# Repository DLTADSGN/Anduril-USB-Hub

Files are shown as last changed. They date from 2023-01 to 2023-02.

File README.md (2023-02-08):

# Anduril USB Hub
This project is a USB 2.0 Hub with USB C input and three output ports (2 USB A, 1 USB C).

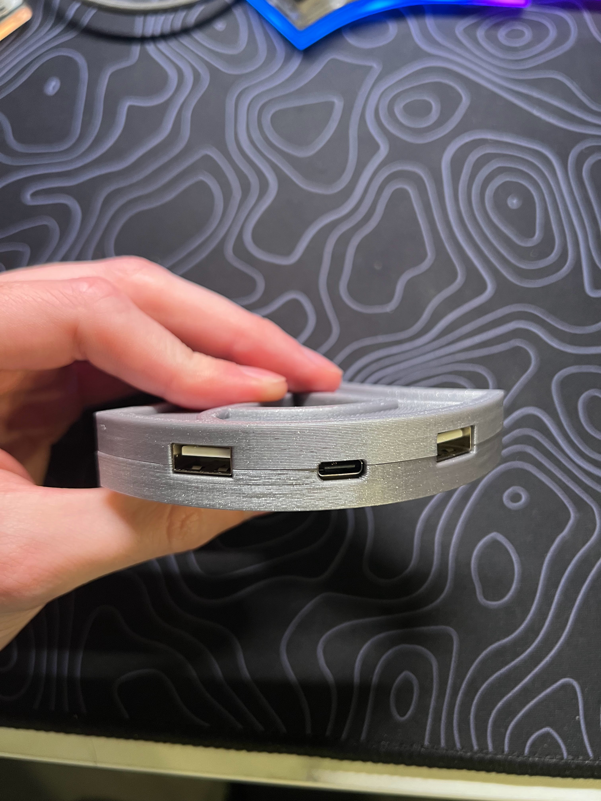
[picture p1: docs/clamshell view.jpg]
Output Ports
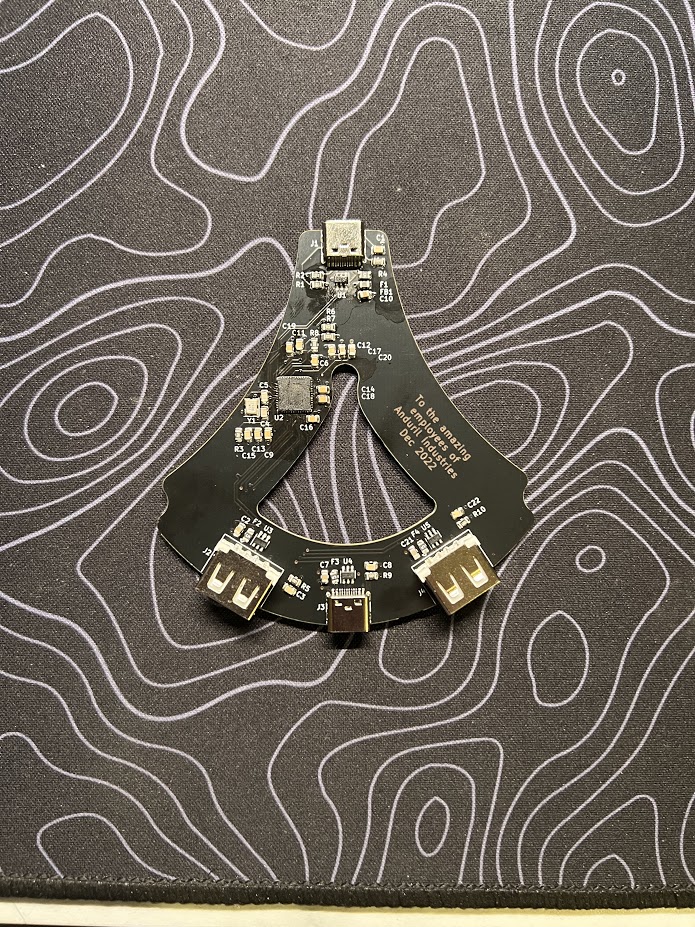
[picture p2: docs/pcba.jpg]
PCBA
Full Assembly  

There isn't much novel about this USB Hub, the main challenge was the layout and packaging to get it to fit in the shape of the [Anduril Industries](https://www.anduril.com/) logo:

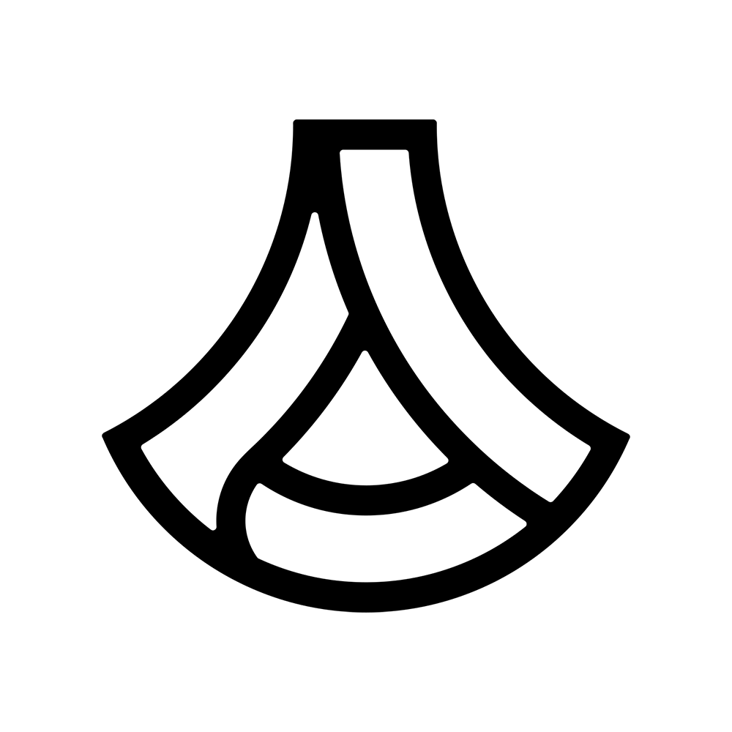
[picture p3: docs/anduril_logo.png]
Anduril Industries Logo


The PCB is designed to fit in a 3D printed, two part housing that screws together to make the Anduril Industries logo. The upstream/host of the hub is at the top and the downstream/peripheral ports are at the bottom.

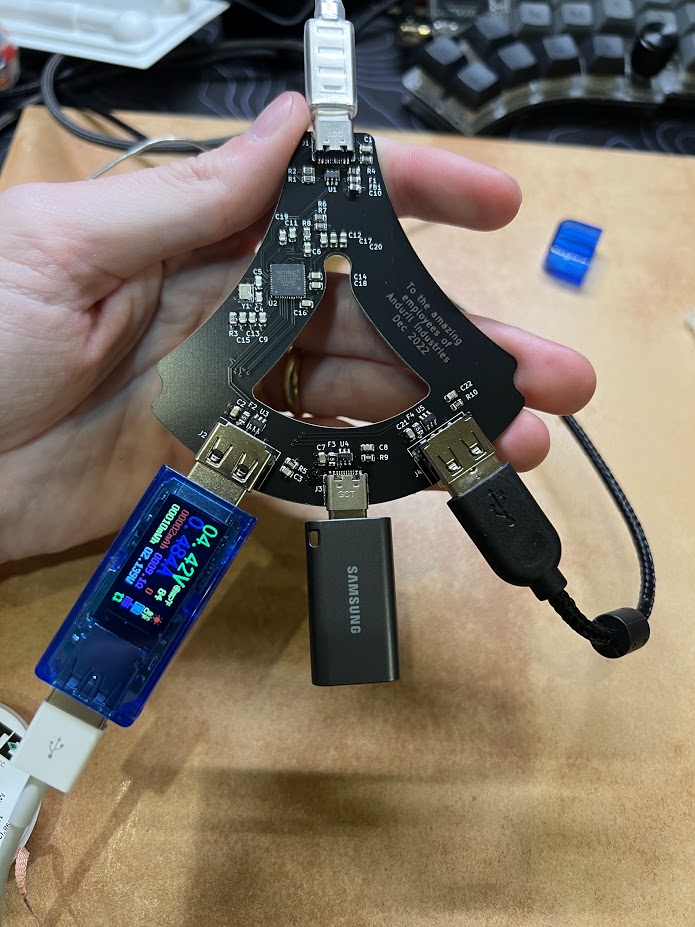
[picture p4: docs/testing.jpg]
Anduril Industries Logo 
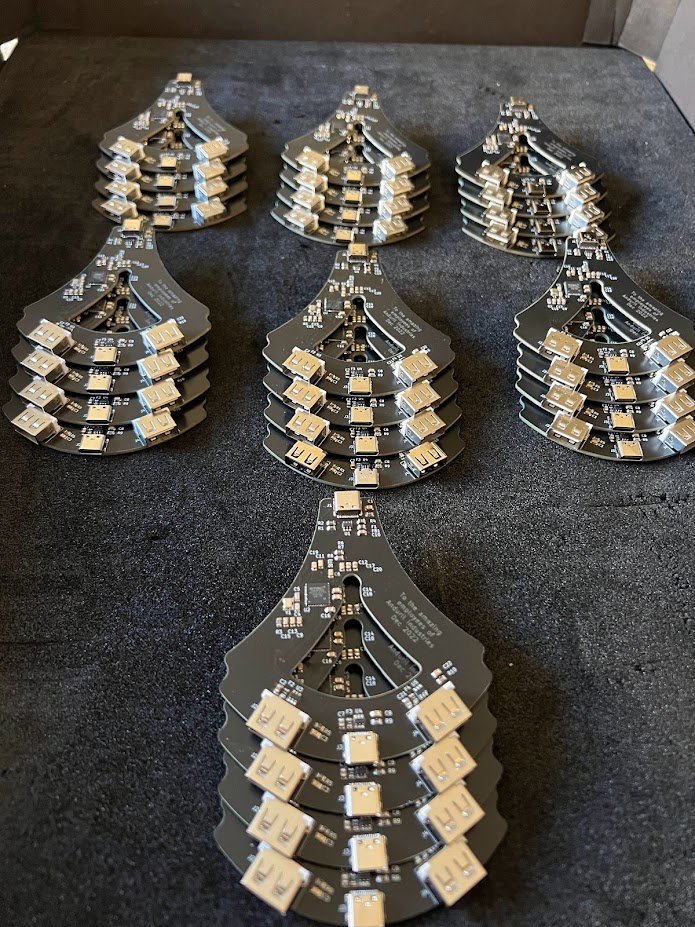
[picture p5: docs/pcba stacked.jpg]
Completed PCBAs


## **REQUIREMENTS**:
 - **USB 2.0 minimum**: USB 3.0+ is outside of my skill set currently, so I stuck with USB 2.0 which should be fast enough for most peripherals and data transfer.
 - **A and C ports**: This was trivial but allows the hub to be used for all sorts of devices, including USB C flash drives.
 - **Safety**: Since this is a gift to my coworkers, I wanted the upmost confidence that the devices they plugged in would not get fried by my creation. To ensure this, I added TVS diodes and fuses on every connector for surge protection and over-current protection.
 - **3D printed enclosure**: Since I just got a 3D printer, I wanted to use it to make the housings in the shape of the Anduril logo. This provided me some great practice/challenge in designing PCBs with mechanical constraints. Additionally, this helped me refine a workflow for electro-mechanical integration.

## **WISHLIST**:
### v1.2
- controlled impedence/differential pair routing
- better testing procedure
- downstream UCB C resistors
- fix silkscreen for fuses
### v2.0
- 2 layer for cheaper manufacturing
- controlled impedence/differential pair routing
- better IC selection (USB2514)

## **LICENSE**:
There is **NO** license for reproduction of the Anduril logo. I do not have any rights or permission to reproduce the Anduril logo in any form and am making this at my own risk.

The electronics of Anduril USB Hub</span> by <a xmlns:cc="http://creativecommons.org/ns#" href="https://github.com/colonDdesigns" property="cc:attributionName" rel="cc:attributionURL">colonDdesigns</a> is licensed under a <a rel="license" href="http://creativecommons.org/licenses/by-nc-sa/4.0/">Creative Commons Attribution-NonCommercial-ShareAlike 4.0 International License</a>.

[][cc-by-nc-sa]

[cc-by-nc-sa]: http://creativecommons.org/licenses/by-nc-sa/4.0/
[cc-by-nc-sa-image]: https://licensebuttons.net/l/by-nc-sa/4.0/88x31.png

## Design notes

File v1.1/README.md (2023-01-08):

# Anduril USB Hub
 
[mechanical](./mechanical/) for Solidworks/STEP files

[electrical](./electrical/) for KiCad files/schematic

[manufacturing](./manufacturing/) for gerbers/BOM/3D print files

enjoy!

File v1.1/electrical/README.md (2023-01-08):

# Electrical

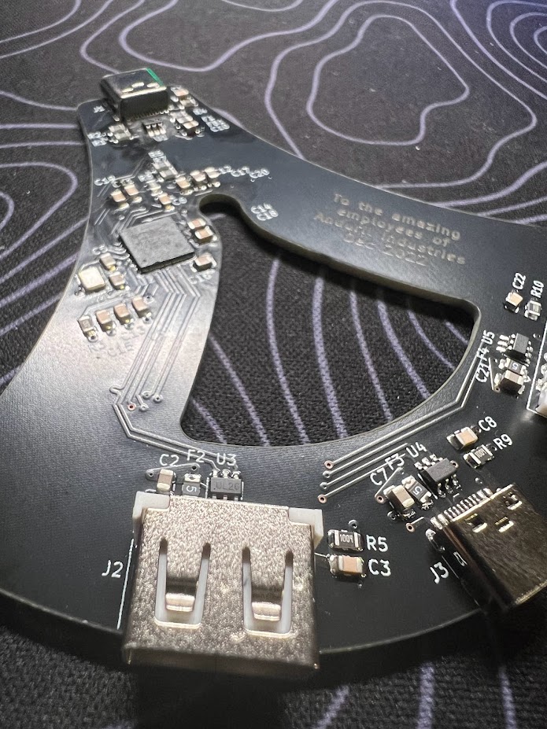
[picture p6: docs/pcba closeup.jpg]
PCBA closeup
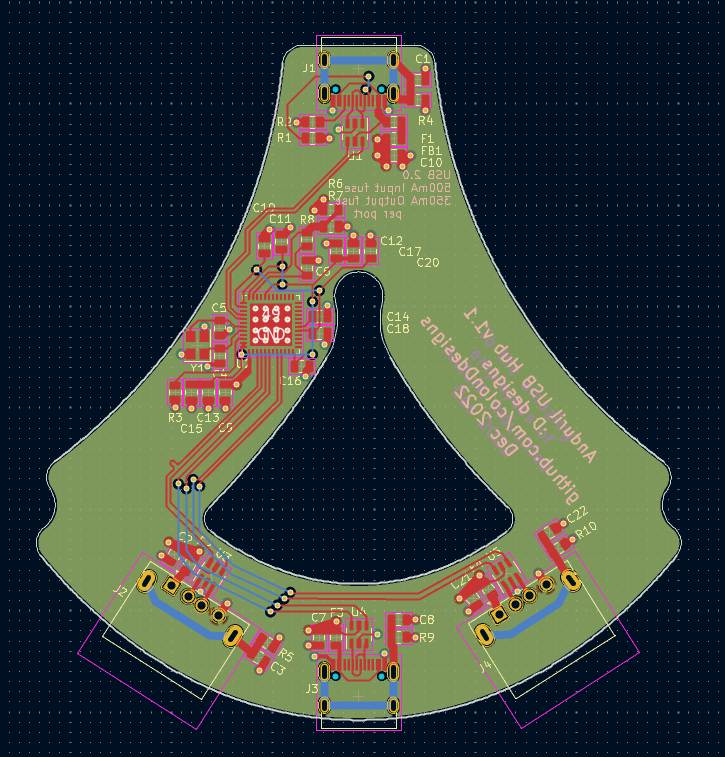
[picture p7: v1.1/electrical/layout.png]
Layout
 PCBA  

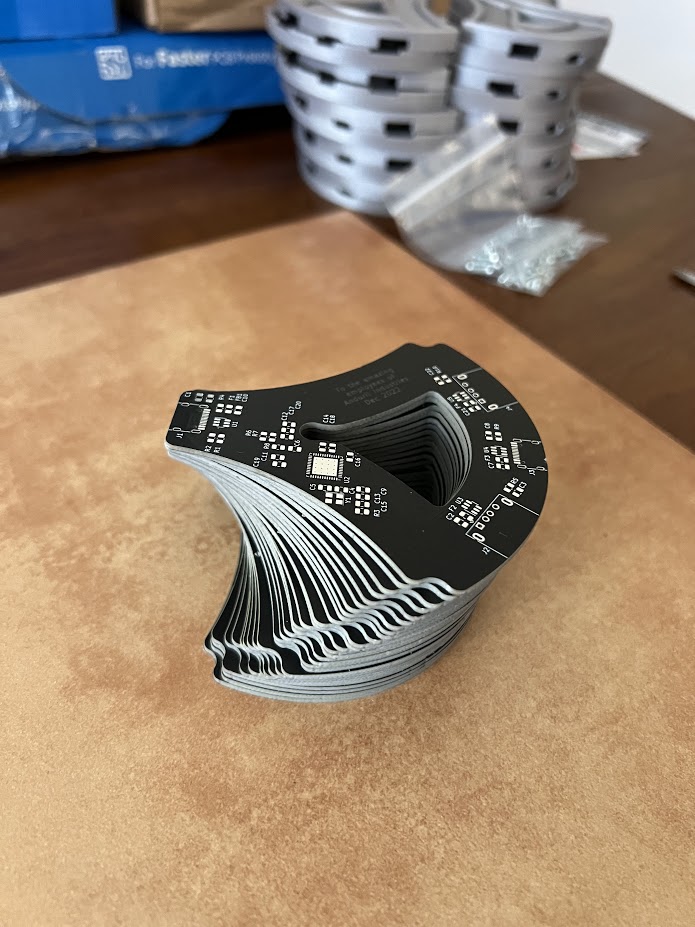
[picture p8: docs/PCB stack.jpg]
PCB Stack
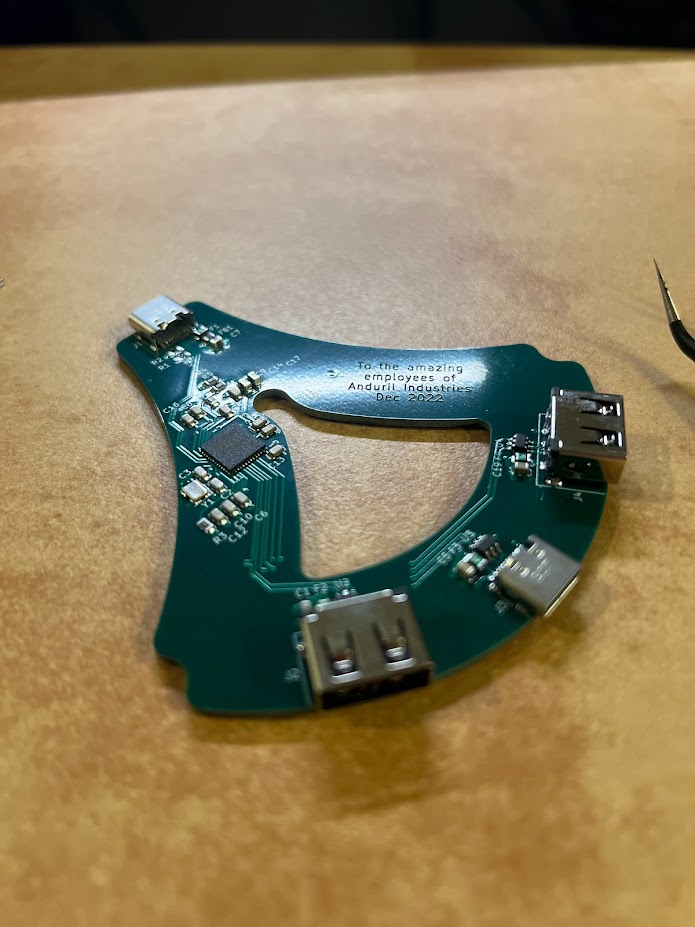
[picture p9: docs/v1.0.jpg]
v1.0
 Testing

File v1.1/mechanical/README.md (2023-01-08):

# Mechanical

Upper and Lower PCBA in Lower 

Black and Silver Port View

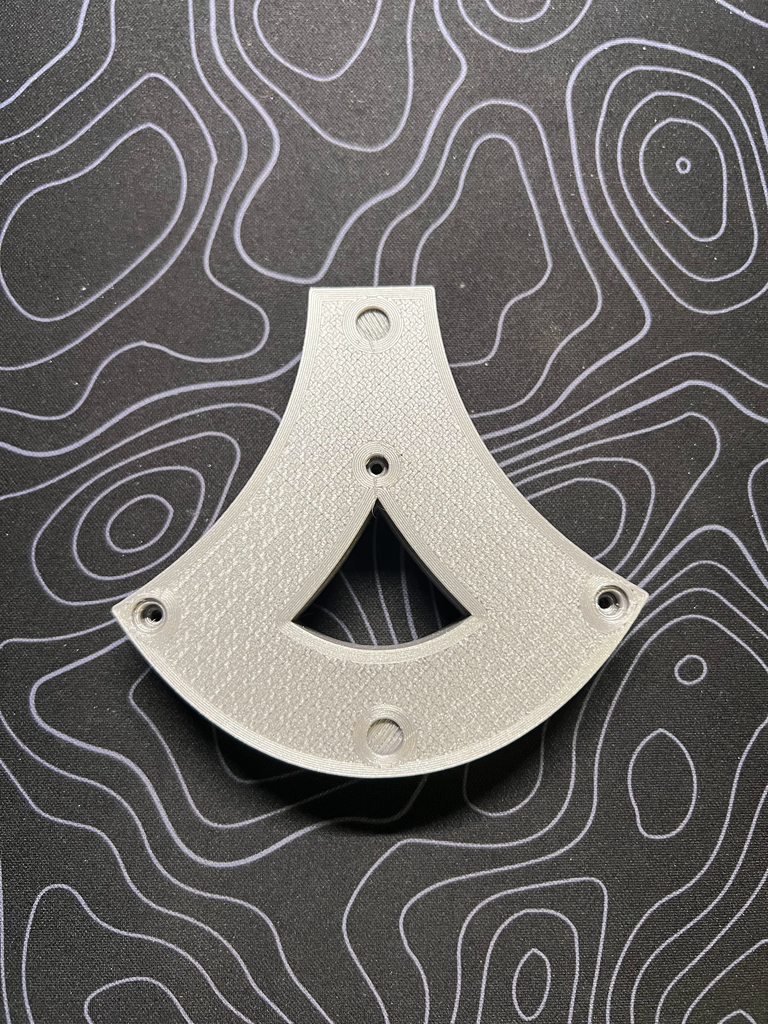
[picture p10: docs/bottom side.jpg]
Bottom Side
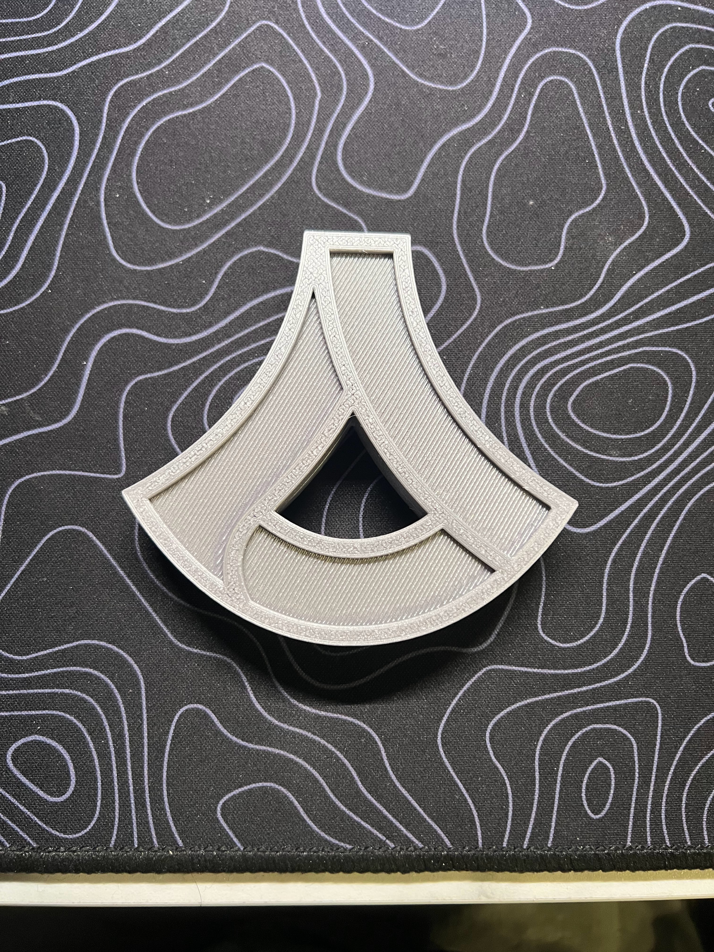
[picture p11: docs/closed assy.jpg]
Top Side


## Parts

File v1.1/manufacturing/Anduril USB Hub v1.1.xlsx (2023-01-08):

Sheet: v1.1 Detail BOM
Anduril USB Hub
Assembly | Description/Use | Manufactuer | Manufactuerer PN | Vendor | Vendor PN | Qty Needed per 1 Assy | Qty Needed per 25 Assy | Qty per 1 Order | Cost per 1 Order | Qty ordered | Total Qty ordered | Cost ext | Link | Package/Footprint | Datasheet | Notes | Order # | Tracking # | Status | ETA
PCB Component | USB Controller IC | Microchip | USB4604-1080HN | Mouser | 579-USB4604-1080HN | 1 | 25 | 1 | 5.39 | 27 | 27 | 145.53 | https://www.mouser.com/ProductDetail/Microchip-Technology-Atmel/USB4604-1080HN?qs=Yyy8avaXlIsjmKTrefWvVw%3D%3D | SQFN-48 | https://www.mouser.com/datasheet/2/268/000001716C_-1512886.pdf | -
PCB Component | 24MHz Crystal | JGHC | S3224000081040D1JB | LCSC | C700764 | 1 | 25 | 5 | 0.38 | 6 | 30 | 2.28 | https://www.lcsc.com/product-detail/Crystals_JGHC-S3224000081040D1JB_C700764.html | SMD3225-4P | https://datasheet.lcsc.com/lcsc/2008261934_JGHC-S3224000081040D1JB_C700764.pdf | -
PCB Component | 5k1Ohm Resistor | UNI-ROYAL | 0805W8F5101T5E | LCSC | C27834 | 2 | 50 | 100 | 0.17 | 1 | 100 | 0.17 | https://www.lcsc.com/product-detail/Chip-span-style-background-color-ff0-Resistor-span-Surface-Mount_UNI-ROYAL-Uniroyal-Elec-0805W8F5101T5E_C27834.html | 0805 | https://datasheet.lcsc.com/lcsc/2206010030_UNI-ROYAL-Uniroyal-Elec-0805W8F5101T5E_C27834.pdf | -
PCB Component | 10kOhm Resistor | UNI-ROYAL | 0805W8F1002T5E | LCSC | C17414 | 1 | 25 | 100 | 0.08 | 1 | 100 | 0.08 | https://www.lcsc.com/product-detail/Chip-span-style-background-color-ff0-Resistor-span-Surface-Mount_UNI-ROYAL-Uniroyal-Elec-0805W8F1002T5E_C17414.html | 0805 | https://datasheet.lcsc.com/lcsc/2206010216_UNI-ROYAL-Uniroyal-Elec-0805W8F1002T5E_C17414.pdf | -
PCB Component | 12kOhm Resistor | UNI-ROYAL | 0805W8F1202T5E | LCSC | C17444 | 1 | 25 | 100 | 0.17 | 1 | 100 | 0.17 | https://www.lcsc.com/product-detail/Chip-span-style-background-color-ff0-Resistor-span-Surface-Mount_UNI-ROYAL-Uniroyal-Elec-0805W8F1202T5E_C17444.html | 0805 | https://datasheet.lcsc.com/lcsc/2206010216_UNI-ROYAL-Uniroyal-Elec-0805W8F1202T5E_C17444.pdf | -
PCB Component | 51kOhm Resistor | UNI-ROYAL | 0805W8F5102T5E | LCSC | C17737 | 1 | 25 | 100 | 0.16 | 1 | 100 | 0.16 | https://www.lcsc.com/product-detail/Chip-span-style-background-color-ff0-Resistor-span-Surface-Mount_UNI-ROYAL-Uniroyal-Elec-0805W8F5102T5E_C17737.html | 0805 | https://datasheet.lcsc.com/lcsc/2206010200_UNI-ROYAL-Uniroyal-Elec-0805W8F5102T5E_C17737.pdf | -
PCB Component | 100kOhm Resistor | UNI-ROYAL | 0805W8F1003T5E | LCSC | C149504 | 1 | 25 | 100 | 0.17 | 1 | 100 | 0.17 | https://www.lcsc.com/product-detail/Chip-span-style-background-color-ff0-Resistor-span-Surface-Mount_UNI-ROYAL-Uniroyal-Elec-0805W8F1003T5E_C149504.html | 0805 | https://datasheet.lcsc.com/lcsc/2205312316_UNI-ROYAL-Uniroyal-Elec-0805W8F1003T5E_C149504.pdf | -
PCB Component | 1MOhm Resistor | UNI-ROYAL | 0805W8F1004T5E | LCSC | C17514 | 4 | 100 | 100 | 0.17 | 2 | 200 | 0.34 | https://www.lcsc.com/product-detail/Chip-Resistor-Surface-Mount_UNI-ROYAL-Uniroyal-Elec-0805W8F1004T5E_C17514.html | 0805 | https://datasheet.lcsc.com/lcsc/2206010200_UNI-ROYAL-Uniroyal-Elec-0805W8F1004T5E_C17514.pdf | -
PCB Component | 8pF Capacitor | FH | 0805CG8R0C500NT | LCSC | C1839 | 2 | 50 | 100 | 0.56 | 1 | 100 | 0.56 | https://www.lcsc.com/product-detail/Multilayer-Ceramic-Capacitors-MLCC-SMD-SMT_FH-Guangdong-Fenghua-Advanced-Tech-0805CG8R0C500NT_C1839.html | 0805 | https://datasheet.lcsc.com/lcsc/1811061741_FH--Guangdong-Fenghua-Advanced-Tech-0805CG8R0C500NT_C1839.pdf | -
PCB Component | 0.1uF Capacitor | Torch | C0805B104K500NT | LCSC | C476766 | 14 | 350 | 100 | 0.38 | 4 | 400 | 1.52 | https://www.lcsc.com/product-detail/Multilayer-Ceramic-Capacitors-MLCC-SMD-SMT_TORCH-C0805B104K500NT_C476766.html | 0805 | https://datasheet.lcsc.com/lcsc/1912300933_TORCH-C0805B104K500NT_C476766.pdf | -
PCB Component | 1uF Capacitor | Samsung Electro-Mechanics | CL21B105KBFNNNE | LCSC | C28323 | 3 | 75 | 50 | 0.43 | 2 | 100 | 0.86 | https://www.lcsc.com/product-detail/Multilayer-Ceramic-Capacitors-MLCC-SMD-SMT_Samsung-Electro-Mechanics-CL21B105KBFNNNE_C28323.html | 0805 | https://datasheet.lcsc.com/lcsc/1810191216_Samsung-Electro-Mechanics-CL21B105KBFNNNE_C28323.pdf | -
PCB Component | 4.7uF Capacitor | Samsung Electro-Mechanics | CL21A475KAQNNNE | LCSC | C1779 | 3 | 75 | 50 | 0.5 | 2 | 100 | 1 | https://www.lcsc.com/product-detail/Multilayer-Ceramic-Capacitors-MLCC-SMD-SMT_Samsung-Electro-Mechanics-CL21A475KAQNNNE_C1779.html | 0805 | https://datasheet.lcsc.com/lcsc/1810261822_Samsung-Electro-Mechanics-CL21A475KAQNNNE_C1779.pdf | -
PCB Component | 750mA Fuse | Brightking | SMD0805B075TF | LCSC | C269105 | 3 | 75 | 20 | 0.42 | 5 | 100 | 2.1 | https://www.lcsc.com/product-detail/Resettable-Fuses_Brightking-SMD0805B075TF_C269105.html | 0805 | https://datasheet.lcsc.com/lcsc/1808280518_Brightking-SMD0805B075TF_C269105.pdf | -
PCB Component | 1.1A Fuse | Brightking | SMD0805B110TF | LCSC | C269107 | 1 | 25 | 20 | 0.58 | 2 | 40 | 1.16 | https://www.lcsc.com/product-detail/Resettable-Fuses_Brightking-SMD0805B110TF_C269107.html | 0805 | https://datasheet.lcsc.com/lcsc/1810161745_Brightking-SMD0805B110TF_C269107.pdf | -
PCB Component | TVS Diode | TECH PUBLIC | USBLC6-2SC6 | LCSC | C2827654 | 4 | 100 | 10 | 0.66 | 12 | 120 | 7.92 | https://www.lcsc.com/product-detail/ESD-Protection-Devices_TECH-PUBLIC-USBLC6-2SC6_C2827654.html | SOT-23-6 | https://datasheet.lcsc.com/lcsc/2108132230_TECH-PUBLIC-USBLC6-2SC6_C2827654.pdf | -
PCB Component | USB A Connector | Jing Extension of the Electronic Co | 912-221A1011D10100 | LCSC | C42459 | 2 | 50 | 10 | 0.47 | 6 | 60 | 2.82 | https://www.lcsc.com/product-detail/USB-Connectors_Jing-Extension-of-the-Electronic-Co-912-221A1011D10100_C42459.html | Connector | https://datasheet.lcsc.com/lcsc/2102261734_Jing-Extension-of-the-Electronic-Co--912-221A1011D10100_C42459.pdf | -
PCB Component | USB C Connector | Korean Hroparts Elec | TYPE-C-31-M-12 | LCSC | C165948 | 2 | 50 | 5 | 1.14 | 11 | 55 | 12.54 | https://www.lcsc.com/product-detail/USB-Connectors_Korean-Hroparts-Elec-TYPE-C-31-M-12_C165948.html | Connector | https://datasheet.lcsc.com/lcsc/2205251630_Korean-Hroparts-Elec-TYPE-C-31-M-12_C165948.pdf | -
PCB Component | 600Ohm Ferrite Bead | Sunlord | GZ2012D601TF | LCSC | C1017 | 1 | 25 | 50 | 0.45 | 1 | 50 | 0.45 | https://www.lcsc.com/product-detail/span-style-background-color-ff0-Ferrite-span-Beads_Sunlord-GZ2012D601TF_C1017.html | 0805 | https://datasheet.lcsc.com/lcsc/2109181830_Sunlord-GZ2012D601TF_C1017.pdf | -
PCB Fab | PCB Board + Stencil | JLCPCB | - | JLCPCB | - | 1 | 25 | 1 | 56.54 | 25 | 25 | 56.54 | - | - | - | -
Hardware | M2 Heat Set Insert | Hilitchi | - | Amazon | B07VBRF7P2 | 3 | 75 | 100 | 7.99 | 1 | 100 | 7.99 | https://www.amazon.com/dp/B07VBRF7P2?ref=ppx_yo2ov_dt_b_product_details&th=1 | - |  | -
Hardware | M2x4mm SHCS | - | - | Anduril | - | 2 | 50 | 100 | 15.76 | 1 | 100 | 15.76 | - | - | - | -
Hardware | M2x6mm SHCS | - | - | Anduril | - | 1 | 25 | 100 | 9.97 | 1 | 100 | 9.97 | - | - | - | -
Hardware | Bumpons, 6mm x 2mm | - | - | Amazon | B073SVKFYJ | 4 | 100 | 200 | 5.99 | 1 | 200 | 5.99 | https://www.amazon.com/gp/product/B073SVKFYJ/ref=ppx_od_dt_b_asin_title_s00?ie=UTF8&th=1 | - | - | -
Hardware | USB Housing, Lower | :D Designs | - | - | - | 1 | 25 | 1 | 0.4 | 25 | 25 | 10 | - | - | - | -
Hardware | USB Housing, Upper | :D Designs | - | - | - | 1 | 25 | 1 | 0.4 | 25 | 25 | 10 | - | - | - | -
Tooling | Heat Set Insert Tips | - | - | Amazon | B08B17VQLD | 1 | 1 | 1 | 19.95 | 1 | 1 | 19.95 | - | - | - | -
Tooling | USB C Male Terminal | - | - | Amazon | B08D93ZSM4 | 2 | 2 | 1 | 7.5 | 2 | 2 | 15 | https://www.amazon.com/gp/product/B08D93ZSM4/ref=ppx_yo_dt_b_asin_title_o00_s00?ie=UTF8&th=1 | - | - | -
Tooling | USB A Male Terminal | - | - | Amazon | B0BPC7DZM1 | 2 | 2 | 2 | 10.99 | 1 | 2 | 10.99 | https://www.amazon.com/gp/product/B0BPC7DZM1/ref=ppx_yo_dt_b_asin_title_o00_s00?ie=UTF8&psc=1 | - | - | -
Tooling | Putty Knife | - | - | Amazon | B09955YQJQ | 1 | 1 | 1 | 7.79 | 1 | 1 | 7.79 | https://www.amazon.com/dp/B09955YQJQ?psc=1&ref=ppx_yo2ov_dt_b_product_details | - | - | -
Consumable | 3D Printer Filament, Matte Black | Overture 3D | - | Amazon | B089S2QDHD | 1 | 1 | 1 | 15.99 | 1 | 1 | - | https://www.amazon.com/gp/product/B089S2QDHD/ref=ppx_od_dt_b_asin_title_s01?ie=UTF8&th=1 | - | - | -
Consumable | Green Stickers | Avery | - | Amazon | B0000859WQ | 1 | 1 | 450 | 3.41 | 1 | 450 | 3.41 | https://www.amazon.com/gp/product/B0000859WQ/ref=ppx_od_dt_b_asin_title_s00?ie=UTF8&th=1 | - | - | -
Consumable | Solder Paste | Chip Quik | TS391AX50 | Mouser | 910-TS391AX50 | 1 | 1 | 15g | 13.95 | 1 | 1 | 13.95 | https://www.mouser.com/ProductDetail/Chip-Quik/TS391AX50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 | - | https://www.mouser.com/datasheet/2/73/TS391AX250-1150217.pdf | -
 |  |  |  |  |  |  |  |  |  |  | Total | 367.17 | 14.69
 |  |  |  |  |  |  |  |  |  |  |  | 115 | 19.29

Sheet: v1.1 Fab
Designator | Value
C1, C3, C6, C8, C9, C11, C12, C13, C14, C15, C16, C18, C19, C22, | .1uF
C2, C7, C21, | 1uF
C4, C5, | 8pF
C10, C17, C20, | 4.7uF
F1, | 1.1A
F2, F3, F4, | 750mA
FB1, | 600Ohm
R1, R2, | 5k1Ohm | 0805W8F5101T5E
R3, | 12kOhm | 0805W8F1202T5E
R4, R5, R9, R10, | 1MOhm | 0805W8F1004T5E
R6, | 50kOhm | 0805W8F5102T5E
R7, | 100kOhm | 0805W8F1003T5E
R8, | 10kOhm | 0805W8F1002T5E
U1, U3, U4, U5, | USBLC6-2SC6
U2, | USB4604-1080HN
Y1, | 24MHz

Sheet: LCSC BOM Export
Total Qty Ordered | Mfr PN | LSCS PN
30 | S3224000081040D1JB | C700764
100 | 0805W8F5101T5E | C27834
100 | 0805W8F1002T5E | C17414
100 | 0805W8F1202T5E | C17444
100 | 0805W8F5102T5E | C17737
100 | 0805W8F1003T5E | C149504
200 | 0805W8F1004T5E | C17514
100 | 0805CG8R0C500NT | C1839
400 | C0805B104K500NT | C476766
100 | CL21B105KBFNNNE | C28323
100 | CL21A475KAQNNNE | C1779
40 | SMD0805B050TF | C269104
80 | SMD0805B035TF | C269103
100 | USBLC6-2SC6 | C2827654
60 | 912-221A1011D10100 | C42459
55 | TYPE-C-31-M-12 | C165948
50 | GZ2012D601TF | C1017

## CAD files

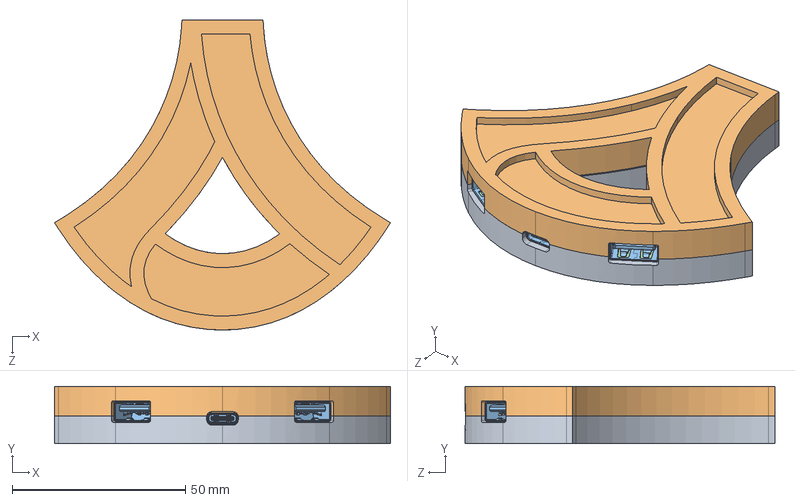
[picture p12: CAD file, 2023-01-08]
v1.1/mechanical/solidworks parts/Assembly, USB Hub.SLDASM
97.1 x 16.5 x 89.6 mm
USB Hub Housing, Lower
USB Hub Housing, Upper
Anduril USB Hub Full - Import 12-7_new
PCB Footprint

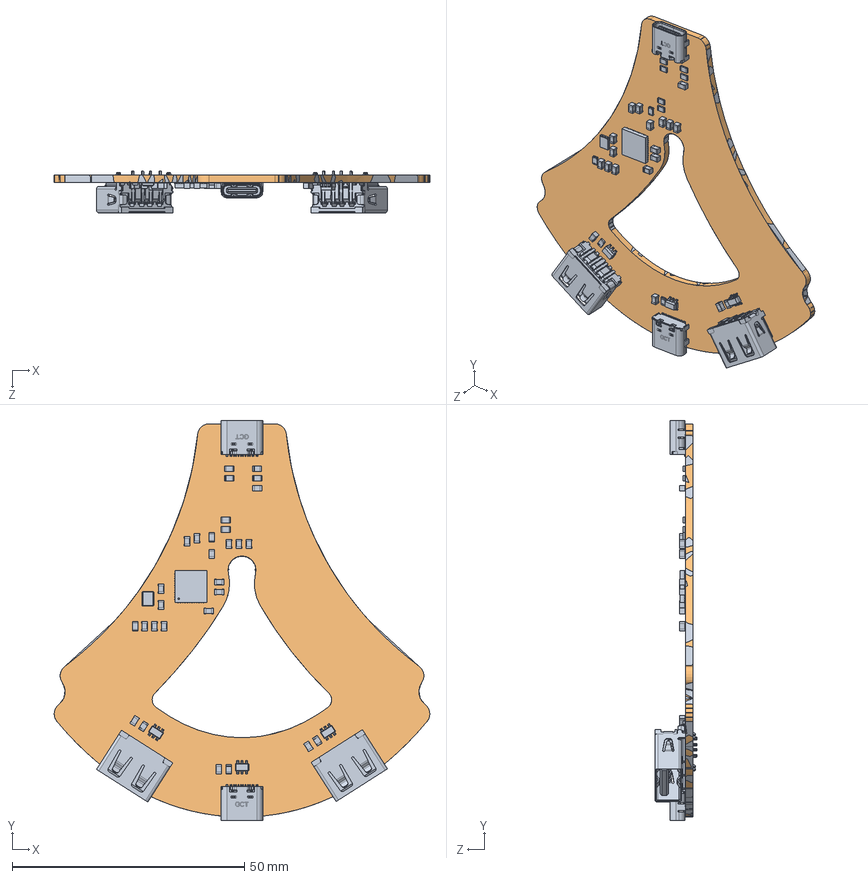
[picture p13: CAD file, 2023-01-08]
v1.1/mechanical/solidworks parts/Assebmly, PCB.SLDASM
80.8 x 86.1 x 9.01 mm
Anduril USB Hub Full - Import 12-7_new
PCB Footprint

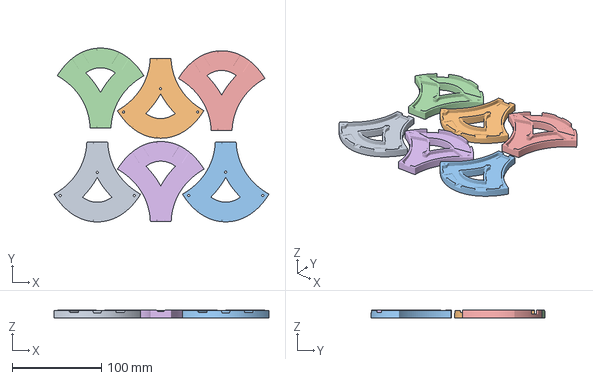
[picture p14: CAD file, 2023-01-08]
v1.1/manufacturing/USB Hub Housing.3mf
241.2 x 195.0 x 8.50 mm
USB Hub Housing, Lower v1.4.STL
USB Hub Housing, Upper v1.5.STL

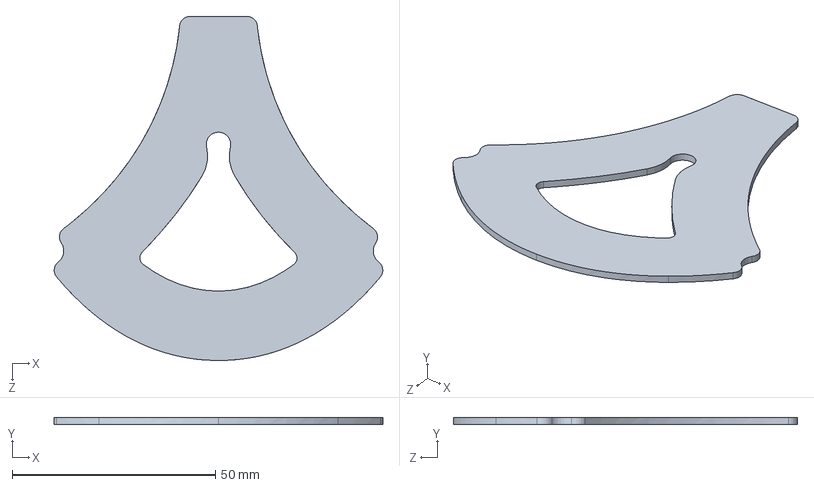
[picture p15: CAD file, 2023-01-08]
v1.1/mechanical/solidworks parts/PCB Footprint.SLDPRT
80.8 x 1.60 x 84.6 mm

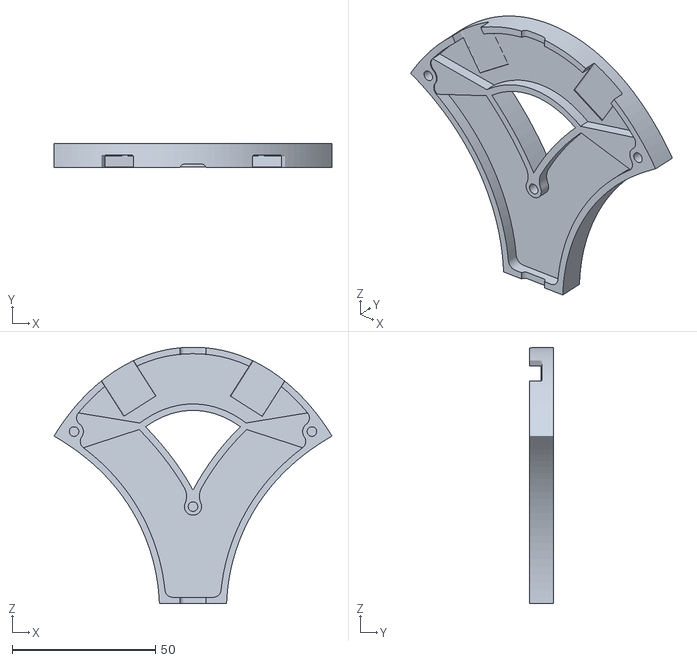
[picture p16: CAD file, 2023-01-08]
v1.1/mechanical/USB Hub Housing, Upper v1.5.STL
97.1 x 8.50 x 89.6

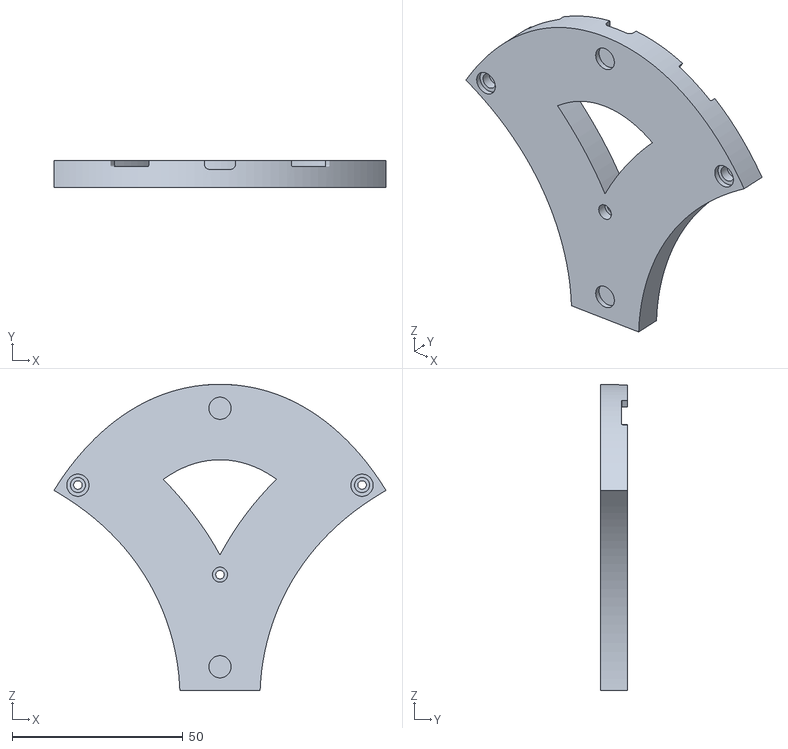
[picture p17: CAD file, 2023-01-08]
v1.1/mechanical/USB Hub Housing, Lower v1.4.STL
97.1 x 8.00 x 89.6

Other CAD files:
v1.1/mechanical/solidworks parts/USB Hub Housing, Upper.SLDPRT
v1.1/mechanical/solidworks parts/USB Hub Housing, Lower.SLDPRT

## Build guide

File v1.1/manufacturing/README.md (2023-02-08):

# Manufacturing

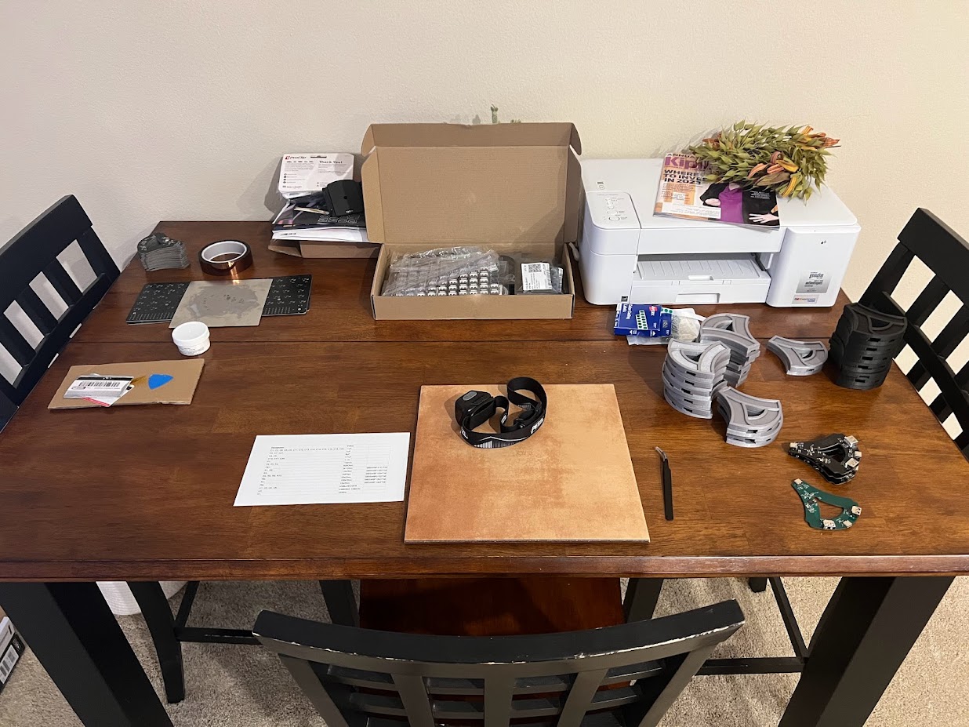
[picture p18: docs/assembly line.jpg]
Assembly Line


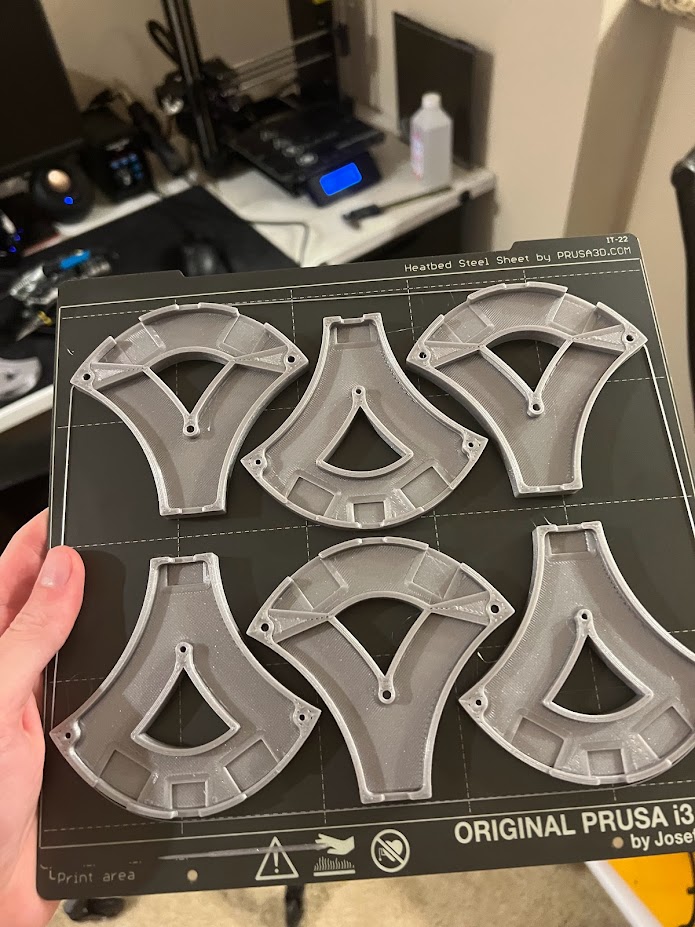
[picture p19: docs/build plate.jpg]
Build Plate
 PCB Stack

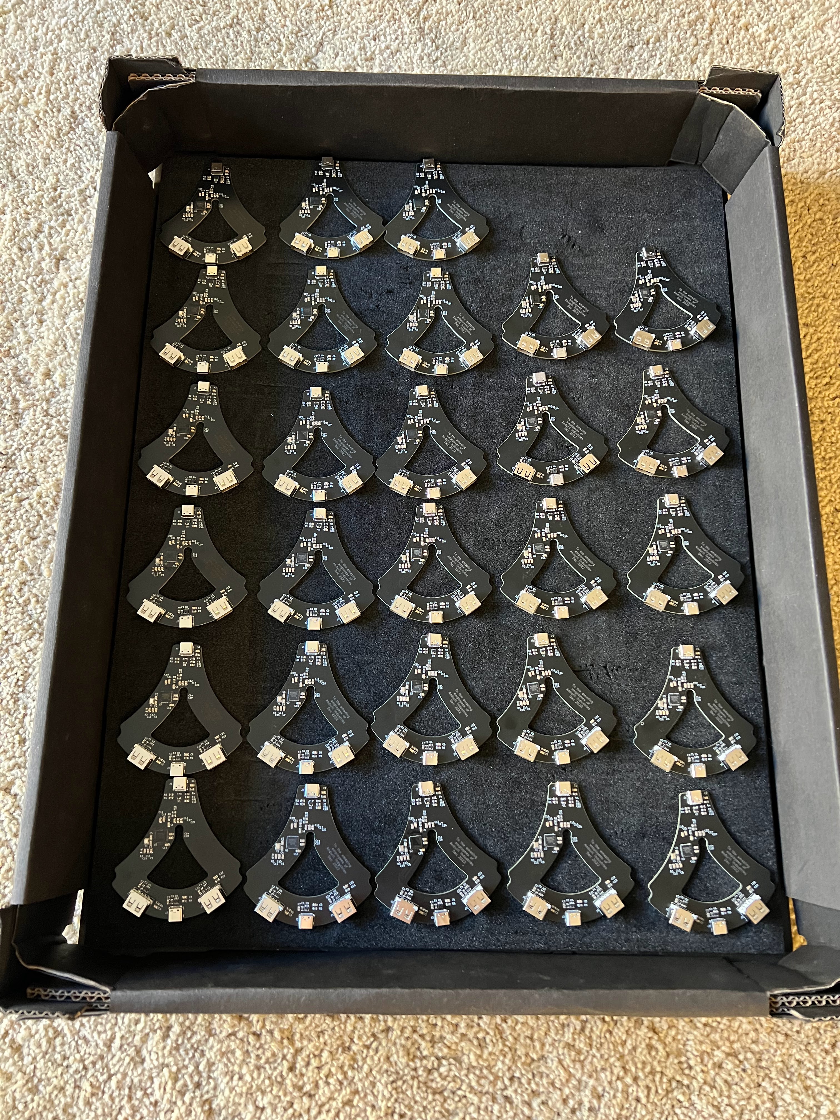
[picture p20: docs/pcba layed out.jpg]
 Completed PCBAs

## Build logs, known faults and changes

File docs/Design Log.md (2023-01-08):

# Electrical
 
- **why USB4604?** Microchip hub controllers had great documentation and application notes so I wanted to go with one of their options. When I started the project the only IC in stock on Mouser/Digikey was the USB4604. I found out when purchasing v1.1 that the USB2514 was available from LCSC for half the cost and a smaller package. Lesson learned...

- **why 4 layer board?** When designing v1.0, I saw that purchasing from JLCPCB at qty 5 was minimal cost difference between 2 vs 4 layer, so I started on a 4 layer stack. It was only when I tried to order at qty 15+ that I realized that JLCPCB added a fixed charge which significantly increased the cost. The design is definitely doable on a 2 layer board, but 4 layer gives a little more solution space. I didn't change to 2 layer for v1.1 because I didn't want to risk changing too much from my successful v1.0.

- **general workflow** I knew I wanted to make a USB Hub in the triangular shape of the Anduril logo, and make it as small as posisble to make it usbale as a usb hub. After importing the logo into solidworks I roughly got a rough housing drawn around the PCB. From there, I imported the PCB outline into KiCad and began designing. This was a big mistake because I still needed to fine tune the size and shape of the PCB and the housing. This meant I needed to redo the layout/routing eachtime I modified the housing. It would have been better if I had fully finalized the mechanicals of the housing and PCB and just did layout and routing one time. This isnt super realistic, but with some better understanding of the rough sizes of the components and one rough pass at just the layout, I couldve cut down a lot of design cycles by finishing the housing and pcb, and then finalizing the layout and completing the routing. additionally, i couldve probably spent more time finalizing the details of the housing (port openings, heat set insert sizing, clearances and interfaces). i spent a lot (too much) time exporting the pcb from KiCAD, to the housing file in Solidworks. Theres definitely some optimization to the workflow there that will ahppen naturally as my inuition and vision for designs improves. i'm very happy with how it turned out and learned a lot about the workflow and integration of pcbs and mechanical housings. the back and forth between KiCAD and SW was exacerbated by the tight constraints on the sizing.

after finalizing the pcb and housing design, i worked on optimizing the 3D printing of th housings since i was going to make 25. because of the qunaitiy, i couldn't modify each and every one in order to make it perfect, otherwise that would take too much time. so the parts need to come off the printer consistently and ready to be assembled. I had to dial in the support material settings to speed up the post processing and ensure consistent results visually. I could nest 3 sets of housings per build plate, which would take 7 hours to print. so by printing overnight, taking off in the morning and starting another print to run during the day. i could print 6 per 24 hours at a 100% yield rate! post processing time was about 3-5 mins per for support removal, heat set insert insertion, and any minor touchups.

- fuses on inputs (500mA upstream and 350mA downstream)
- tvs diodes on all inputs

- 4 layer board
    - signal
    - gnd
    - power
    - signal

- if i routed power i couldve done the perfereed stack of:
    - signal
    - gnd
    - gnd
    - signal

- 0805 components for handplacing, minimal benefit to smaller components
- did not do impedence matching, figured it would be fine without it and v1.0 worked fine without it. tried to match trace lengths. would like to understand more about impedence matching since it seems critical for robust designs

- needed to make housing tighter on pcb for better fit
- make heatset insert holes bigger to minimize the filament squeeze out
- wall thickness to match mulitple of nozzle thickness 

- 2 part housing seemed easiest to design
    - didnt see a need to hold down the PCB in any other way beyond the outer edges and connectors
    - easiest to print with minimal supports
- bumpon feet, hidden screws
- heat set inserts
- extra perimeters to minimize printed spikes that cause gaps in the housing

im sure theres a lot more i'm forgetting. will maybe add to this... please reach out with questions.

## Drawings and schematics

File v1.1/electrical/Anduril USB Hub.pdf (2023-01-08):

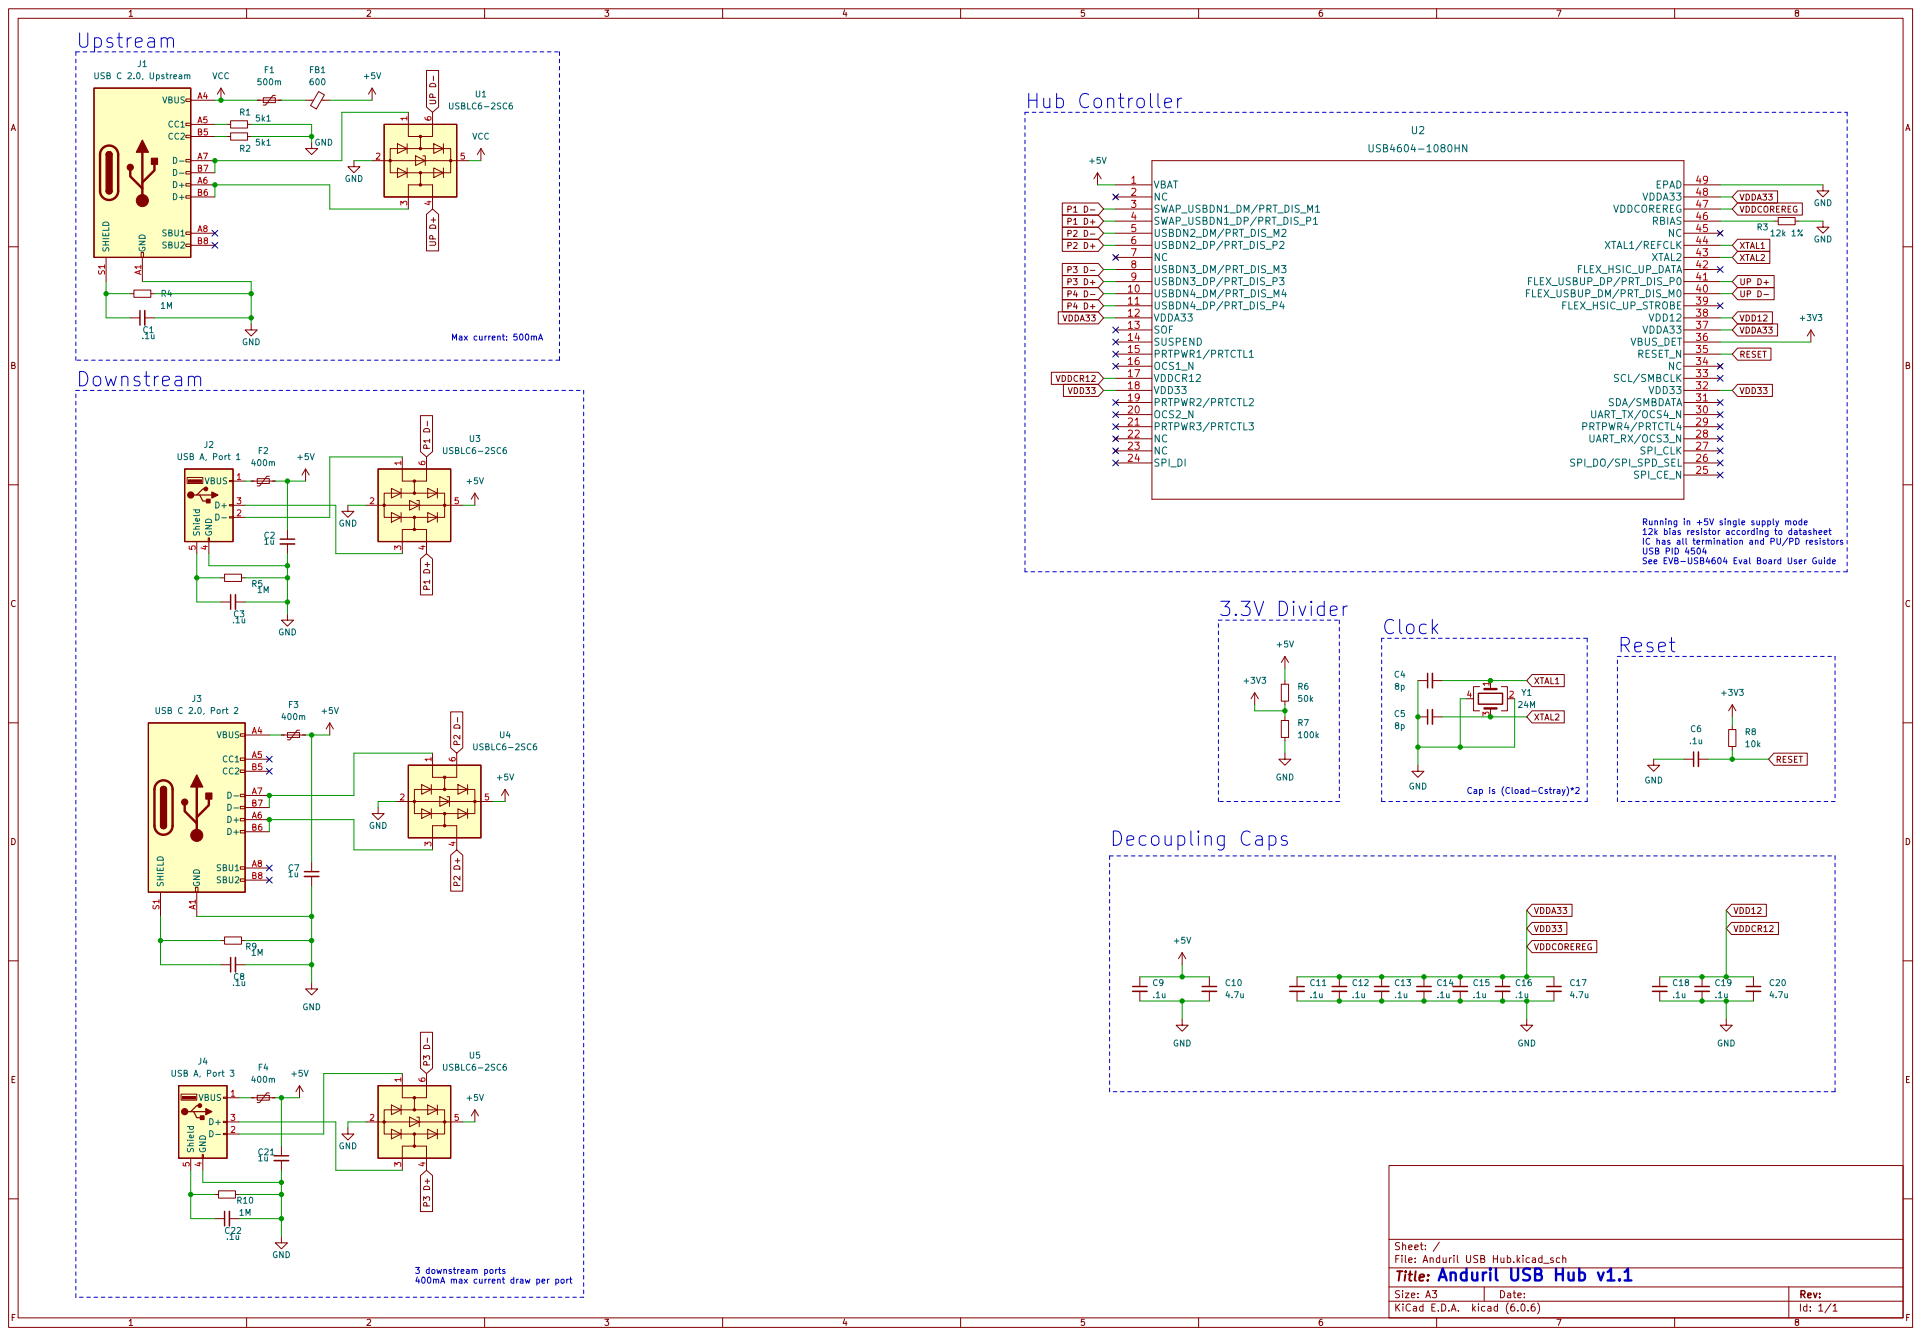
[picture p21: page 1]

Running in +5V single supply mode
12k bias resistor according to datasheet
IC has all termination and PU/PD resistors USB PID 4504 See EVB-USB4604 Eval Board User Guide

Cap is (Cload-Cstray)*2

File: Anduril USB Hub.kicad_sch Sheet: / C21

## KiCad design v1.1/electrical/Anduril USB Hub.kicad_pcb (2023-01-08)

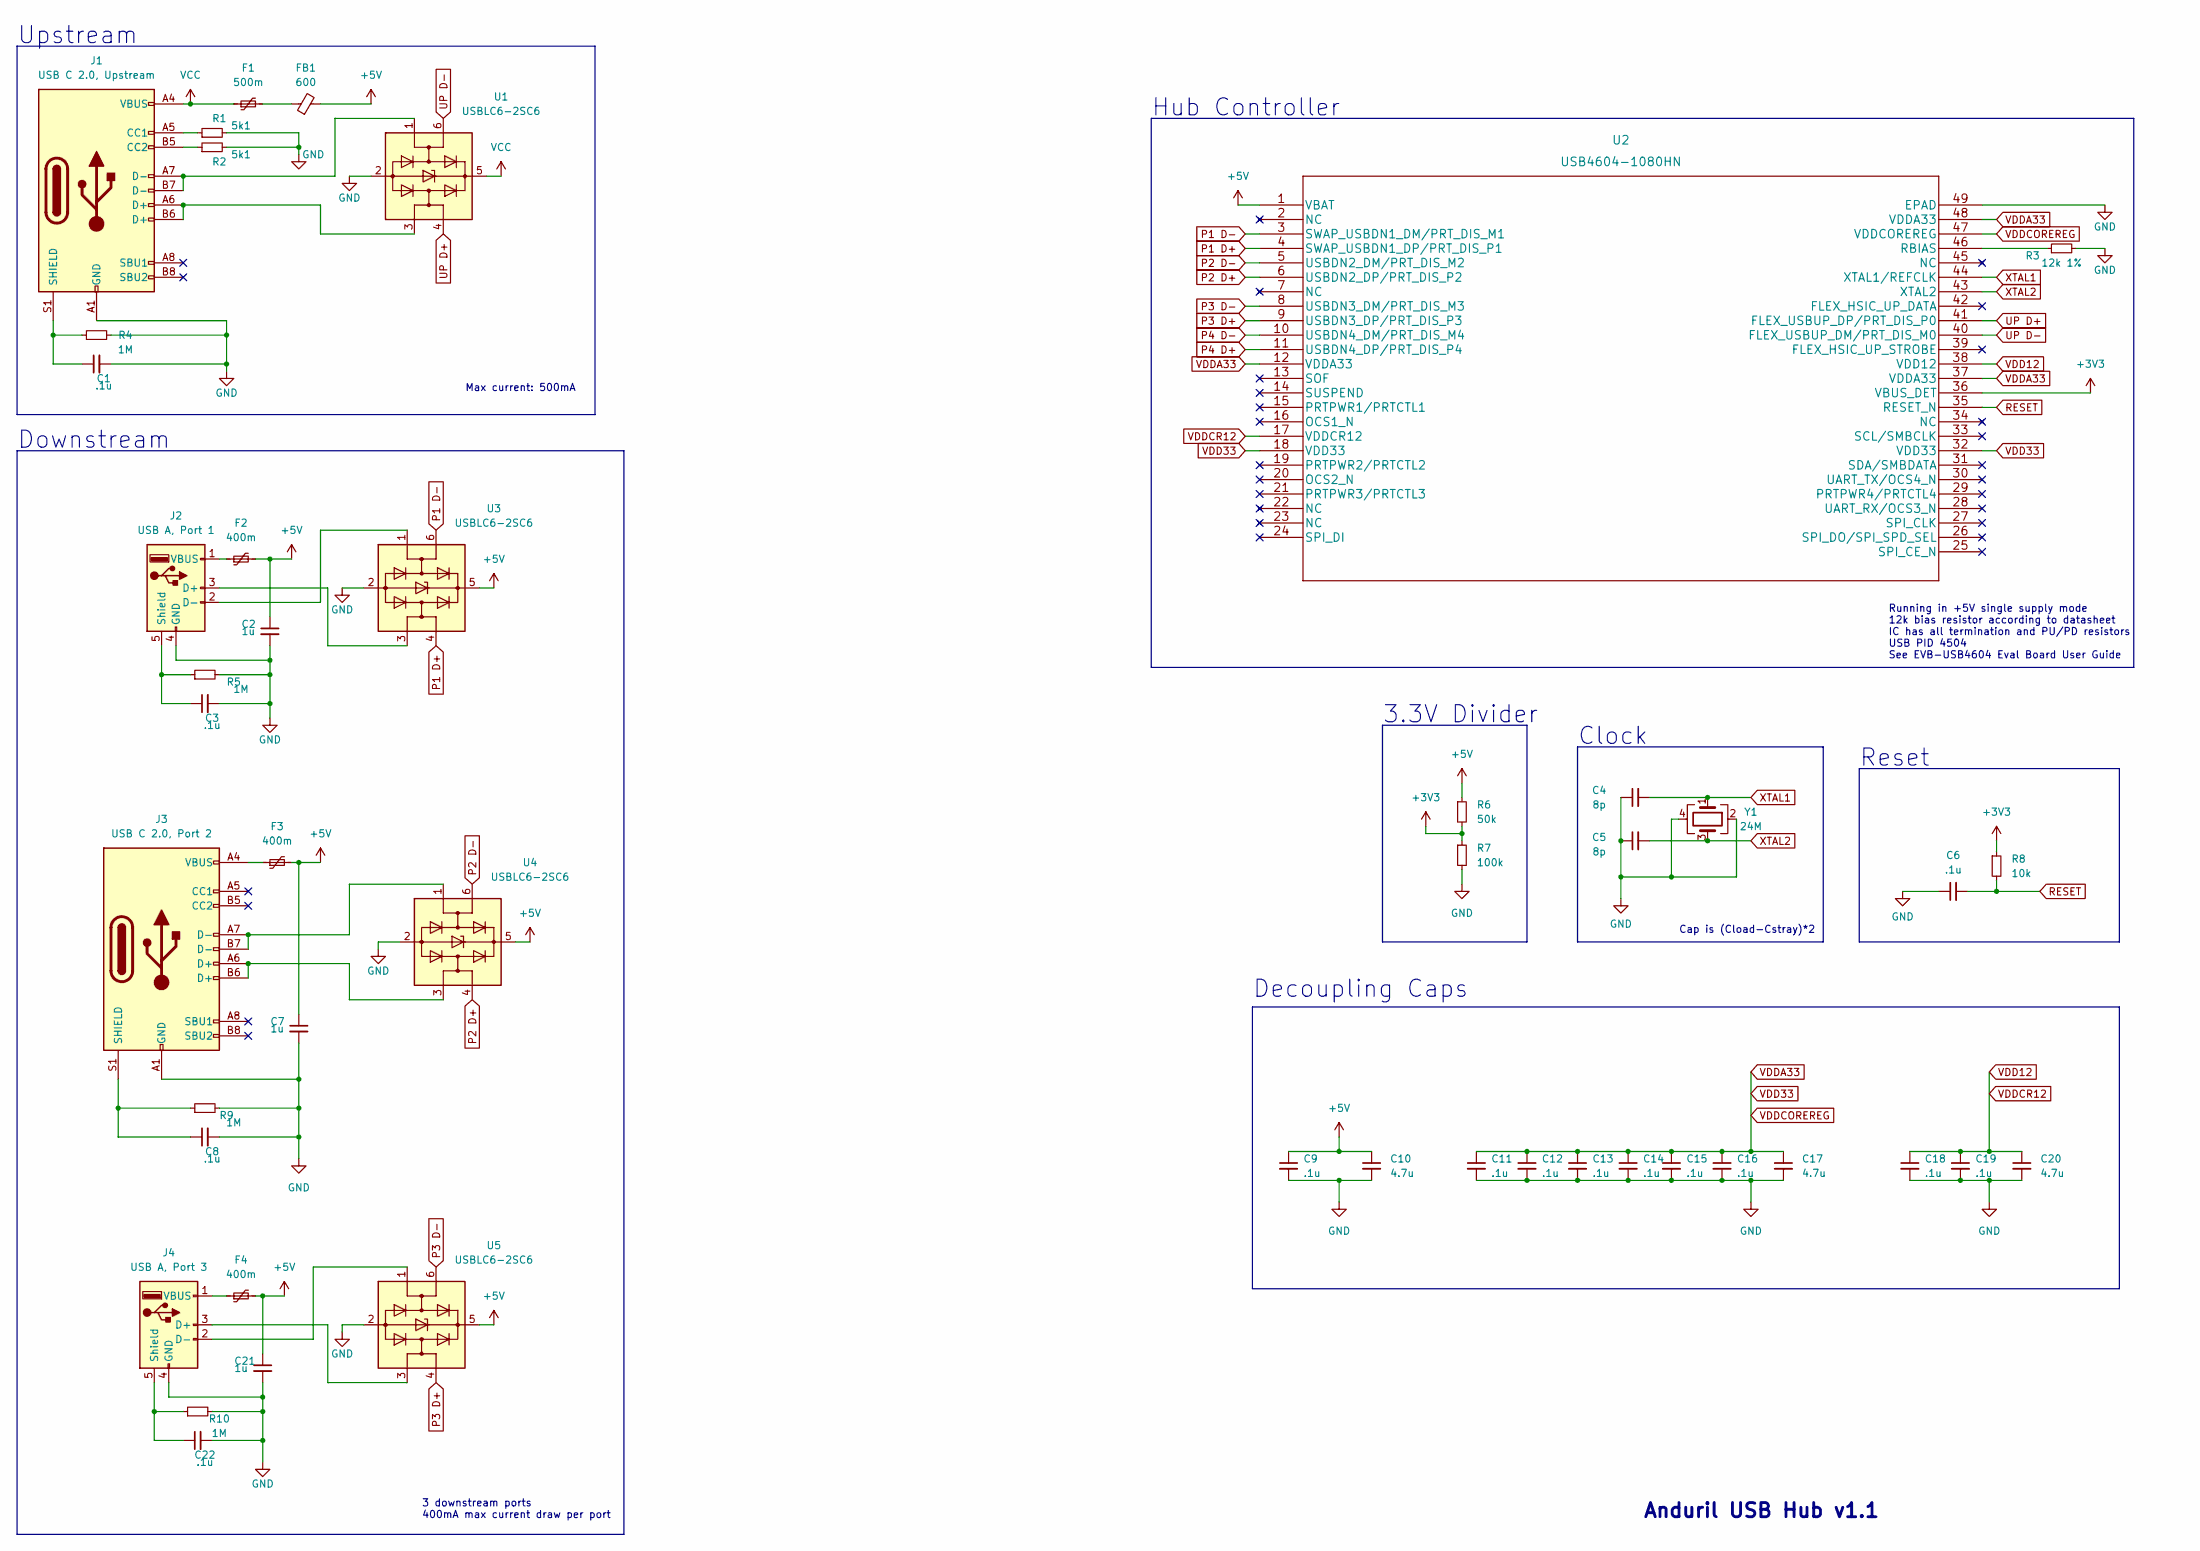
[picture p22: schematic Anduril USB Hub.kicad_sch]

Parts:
C1, C3, C6, C8, C9, C11, C12, C13, C14, C15, C16, C18, C19, C22: .1u; C_0805_2012Metric
C2, C7, C21: 1u; C_0805_2012Metric
C4, C5: 8p; C_0805_2012Metric
C10, C17, C20: 4.7u; C_0805_2012Metric
F1: 500m; Fuse_0805_2012Metric
F2, F3, F4: 400m; Fuse_0805_2012Metric
FB1: 600; R_0805_2012Metric
J1: USB C 2.0, Upstream; USB_C_Receptacle_HRO_TYPE-C-31-M-12
J2: USB A, Port 1; USB_A_CONNFLY_DS1095-WNR0
J3: USB C 2.0, Port 2; USB_C_Receptacle_HRO_TYPE-C-31-M-12
J4: USB A, Port 3; USB_A_CONNFLY_DS1095-WNR0
R1, R2: 5k1; R_0805_2012Metric
R3: 12k 1%; R_0805_2012Metric
R4, R5, R9, R10: 1M; R_0805_2012Metric
R6: 50k; R_0805_2012Metric
R7: 100k; R_0805_2012Metric
R8: 10k; R_0805_2012Metric
U1, U3, U4, U5: USBLC6-2SC6; SOT-23-6
U2: USB4604-1080HN; QFN-48-1EP_7x7mm_P0.5mm_EP5.3x5.3mm
Y1: 24M; Crystal_SMD_3225-4Pin_3.2x2.5mm

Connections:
+3V3: R6.2, R7.1, R8.1, U2.36 (VBUS_DET)
+5V: C2.1, C7.1, C9.1, C10.1, C21.1, F2.2, F3.2, F4.2, FB1.2, R6.1, U2.1 (VBAT), U3.5 (VBUS), U4.5 (VBUS), U5.5 (VBUS)
GND: C1.2, C2.2, C3.2, C4.1, C5.1, C6.1, C7.2, C8.2, C9.2, C10.2, C11.2, C12.2, C13.2, C14.2, C15.2, C16.2, C17.2, C18.2, C19.2, C20.2, C21.2, C22.2, J1.A1 (GND), J1.A12 (GND), J1.B1 (GND), J1.B12 (GND), J2.4 (GND), J3.A1 (GND), J3.A12 (GND), J3.B1 (GND), J3.B12 (GND), J4.4 (GND), R1.2, R2.2, R3.2, R4.2, R5.2, R7.2, R9.2, R10.2, U1.2 (GND), U2.49 (EPAD), U3.2 (GND), U4.2 (GND), U5.2 (GND), Y1.2, Y1.4
unnamed: C1.1, J1.S1 (SHIELD), R4.1
unnamed: C3.1, J2.5 (Shield), R5.1
unnamed: C8.1, J3.S1 (SHIELD), R9.1
unnamed: C22.1, J4.5 (Shield), R10.1
unnamed: F1.2, FB1.1
unnamed: F2.1, J2.1 (VBUS)
unnamed: F3.1, J3.A4 (VBUS), J3.A9 (VBUS), J3.B4 (VBUS), J3.B9 (VBUS)
unnamed: F4.1, J4.1 (VBUS)
unnamed: J1.A5 (CC1), R1.1
unnamed: J1.A6 (D+), J1.B6 (D+), U1.3 (I/O2)
unnamed: J1.A7 (D-), J1.B7 (D-), U1.1 (I/O1)
unnamed: J1.B5 (CC2), R2.1
unnamed: J2.2 (D-), U3.1 (I/O1)
unnamed: J2.3 (D+), U3.3 (I/O2)
unnamed: J3.A6 (D+), J3.B6 (D+), U4.3 (I/O2)
unnamed: J3.A7 (D-), J3.B7 (D-), U4.1 (I/O1)
unnamed: J4.2 (D-), U5.1 (I/O1)
unnamed: J4.3 (D+), U5.3 (I/O2)
unnamed: R3.1, U2.46 (RBIAS)
P1 D+: U2.4 (SWAP_USBDN1_DP/PRT_DIS_P1), U3.4 (I/O2)
P1 D-: U2.3 (SWAP_USBDN1_DM/PRT_DIS_M1), U3.6 (I/O1)
P2 D+: U2.6 (USBDN2_DP/PRT_DIS_P2), U4.4 (I/O2)
P2 D-: U2.5 (USBDN2_DM/PRT_DIS_M2), U4.6 (I/O1)
P3 D+: U2.9 (USBDN3_DP/PRT_DIS_P3), U5.4 (I/O2)
P3 D-: U2.8 (USBDN3_DM/PRT_DIS_M3), U5.6 (I/O1)
P4 D+: U2.11 (USBDN4_DP/PRT_DIS_P4)
P4 D-: U2.10 (USBDN4_DM/PRT_DIS_M4)
RESET: C6.2, R8.2, U2.35 (RESET_N)
UP D+: U1.4 (I/O2), U2.41 (FLEX_USBUP_DP/PRT_DIS_P0)
UP D-: U1.6 (I/O1), U2.40 (FLEX_USBUP_DM/PRT_DIS_M0)
VCC: F1.1, J1.A4 (VBUS), J1.A9 (VBUS), J1.B4 (VBUS), J1.B9 (VBUS), U1.5 (VBUS)
VDD12: C18.1, C19.1, C20.1, U2.17 (VDDCR12), U2.38 (VDD12)
VDD33: C11.1, C12.1, C13.1, C14.1, C15.1, C16.1, C17.1, U2.12 (VDDA33), U2.18 (VDD33), U2.32 (VDD33), U2.37 (VDDA33), U2.47 (VDDCOREREG), U2.48 (VDDA33)
XTAL1: C4.2, U2.44 (XTAL1/REFCLK), Y1.1
XTAL2: C5.2, U2.43 (XTAL2), Y1.3

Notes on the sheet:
Clock
Reset
Anduril USB Hub v1.1
Cap is (Cload-Cstray)*2
3.3V Divider
Hub Controller
Upstream
Downstream
Running in +5V single supply mode 12k bias resistor according to datasheet IC has all termination and PU/PD resistors USB PID 4504 See EVB-USB4604 Eval Board User Guide
Decoupling Caps
3 downstream ports 400mA max current draw per port
Max current: 500mA

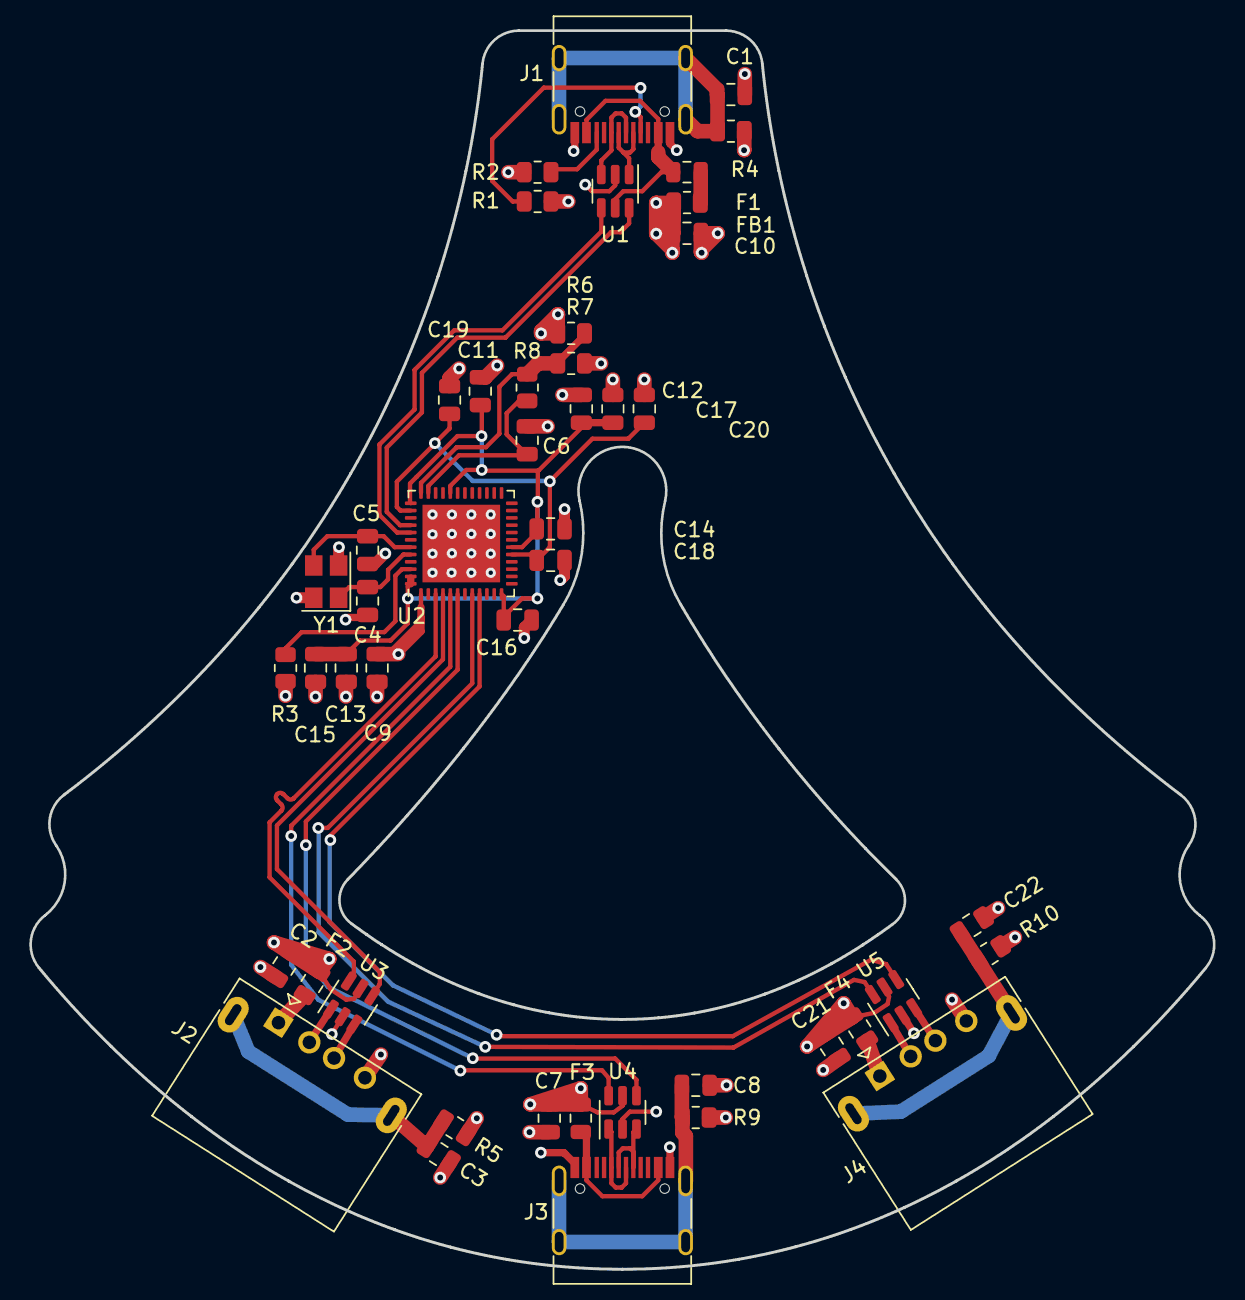
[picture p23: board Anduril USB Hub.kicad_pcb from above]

Board: 4 copper layers, 80.8 x 84.6 mm, 47 parts (0 on the bottom side), 36 nets.

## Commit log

2022-11-26 blah blah comment
    [Anduril USB Hub.kicad_pcb, Anduril USB Hub.kicad_sch]
2022-12-03 layout done, saving for 0805 change
    [Anduril USB Hub.kicad_pcb, Anduril USB Hub.kicad_sch]
2023-01-08 Squashed commit of the following:
    commit f22f3198f381777f4f66884274b8b2f045b28ac8
    Author: sethldaly <seth.daly7531@gmail.com>
    Date: Sat Jan 7 21:56:58 2023 -0800
    added sw parts
    commit 5dc11b7028ca124676168761a285e70834db4c27
    Author: sethldaly <seth.daly7531@gmail.com>
    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
    [Anduril USB Hub v1.0.xlsx, Anduril USB Hub v1.1.xlsx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]

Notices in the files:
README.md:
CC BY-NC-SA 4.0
